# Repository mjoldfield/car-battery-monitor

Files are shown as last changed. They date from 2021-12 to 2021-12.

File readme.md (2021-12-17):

# Car battery monitor

My car tends to eat batteries! Sometimes, particularly during pandemic
summers many weeks pass without the car being used, and during this
time sometimes the battery discharges. I suspect the underlying
problem is that somewhere current is leaking to ground, but that seems
hard to fix. Instead, I’d be happy to just monitor the situation and
charge the battery if needed.

The car is usually parked in range of the home WiFi network, so a
convenient solution would be to have the car send me email about its
battery every once in while.

## code

All written in CircuitPython

## pcb

A PCB to hold tne TinyS2 and DC-DC converter boards, designed in KiCad.

## case

A 3D-printable case designed with OpenSCAD.

# Blog post

See [my blog](https://mjoldfield.com/atelier/2021/12/car-battery-monitor.html) for
more details.

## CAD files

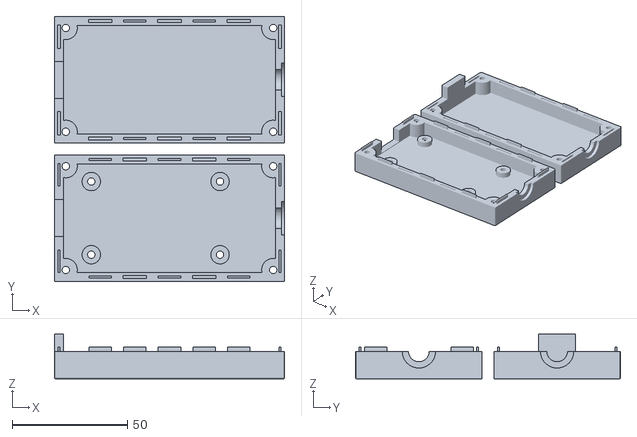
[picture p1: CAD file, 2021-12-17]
case/case.stl
100.0 x 115.0 x 19.5

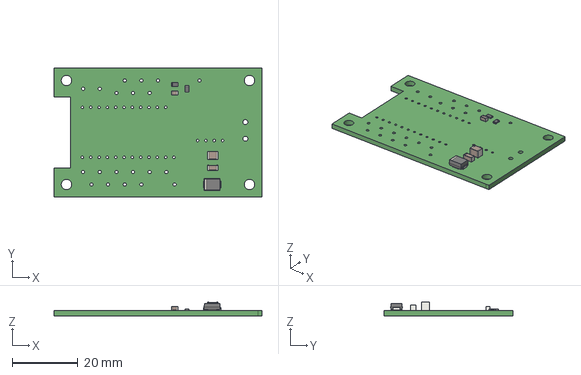
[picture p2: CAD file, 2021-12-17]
pcb/pcb.step
63.5 x 39.4 x 4.15 mm

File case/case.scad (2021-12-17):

include <BOSL/shapes.scad>
include <BOSL/transforms.scad>
include <BOSL/metric_screws.scad>

big   = 200;    // a big number guaranteed to get us out of the box
delta = 1;  // a small number to make sure we go through faces

$fn=50;

wall = 4.0;
size = [100,55,24];
    
board_width  = 65;
board_height = 40;
board_gap    = 0.5;

usb_step     = 0.5;
usb_width    = 16.0;
    
grommet_small = 9;
grommet_width = 2.5;
grommet_big   = 14.5;
    
pcb_mounting_x = 55.88;
pcb_mounting_y = 31.75;
pcb_offset_x   = -6.0;
pcb_offset_y   = 0;
    
standoff_h =  wall + 3.0;
standoff_d =  8;
    
screw_d_thread = 3.2;
screw_h_head   = 3.5;
screw_d_head   = 6.5;
nut_h_head     = 3.5;
nut_d_head     = 6.5;
    
case_screw_inset    =  5.0;
case_screw_diameter = 10.0;

teeth_w     = 1.0;
teeth_h     = 2.0;
teeth_l     = 10.0;
teeth_space = 0.2;
teetha_xs   = [-30,0,30];
teethb_xs   = [-15,15];
teetha_ys   = [-18.75,18.75];
teethb_ys   = [];

module b() {
    
    bd_dx = 0.5 * board_width  + board_gap;
    bd_dy = 0.5 * board_height + board_gap;
    
    cs_dx = 0.5 * size[0] - case_screw_inset;
    cs_dy = 0.5 * size[1] - case_screw_inset;       
    
    insize = size - [2 * wall, 2 * wall, 2 * wall];
    
    pcb_xs = [-0.5 * pcb_mounting_x + pcb_offset_x, 0.5 * pcb_mounting_x + pcb_offset_x];
    pcb_ys = [-0.5 * pcb_mounting_y + pcb_offset_y, 0.5 * pcb_mounting_y + pcb_offset_y];
        
    difference() {
    
        union() {
            difference()  {
                // main box
                cuboid(size, fillet=0.5);

                // hollowed out
                cuboid(insize);
                
                // Cable grommet
                xcyl(l = big, d = grommet_small, center=false);
                right(0.5 * size[0] - (wall - grommet_width))
                    xcyl(l = wall, d = grommet_big, center = false);
            };  
    
            // Mounting standoffs for PCB
            grid3d(xa = pcb_xs,
                   ya = pcb_ys,
                   za=[-0.5 * size[2]])
                cyl(h = standoff_h, d = standoff_d, center=false);
            
            // Screws to hold case together
            intersection() {
                cuboid(size, fillet=0.5);
                grid3d(xa=[-cs_dx,cs_dx], ya=[-cs_dy,cs_dy], za=[-0.5 * size[2]])
                  cyl(h = size[2], d = case_screw_diameter, center=false);
            };
            
        };
        
        // PCB
        span_cube([-bd_dx + pcb_offset_x, bd_dx + pcb_offset_x],
                  [-bd_dy + pcb_offset_y, bd_dy + pcb_offset_y], [
                -0.5 * size[2] + standoff_h,0]);
        
        // Holes in PCB standoffs        
        grid3d(xa=pcb_xs,
               ya=pcb_ys,
               za=[0])
               union() { 
                   down(0.5 * size[2] + delta)
                   union() {
                       cyl(h = standoff_h + 2 * delta, d=screw_d_thread, center=false);
                       cyl(h = screw_h_head + delta,   d=screw_d_head,   center=false);
                   }
               };
               
        // Holes for case screws
        grid3d(xa=[-cs_dx,cs_dx], ya=[-cs_dy,cs_dy], za=[0])
               union() {
                   cyl(h = 2 * big, d=screw_d_thread, center=true);
                   down(big)
                   cyl(h = big - 0.5 * size[2] + screw_h_head,   d=screw_d_head,   center=false);
                   zflip()
                   down(big)
                   cyl(h = big - 0.5 * size[2] + nut_h_head,     d=nut_d_head,     center=false, $fn=6);
               };       
    };
      
            


};


module teeth(xp,yp,xn,yn,pdir) {
    dx = 0.5 * (size[0] - wall);
    dy = 0.5 * (size[1] - wall);
    tlp = 0.5 * (teeth_l - teeth_space);
    tln = 0.5 * (teeth_l + teeth_space);
    twp = 0.5 * (teeth_w - teeth_space);
    twn = 0.5 * (teeth_w + teeth_space);
       
    difference() { 
        union() {
            children();
            grid3d(xa=xp,ya=[-dy,dy],za=[0])
                span_cube([-tlp,tlp],[-twp,twp],[0,pdir * (teeth_h - teeth_space)]); 
            grid3d(xa=[-dx,dx],ya=yp,za=[0])
                span_cube([-twp,twp],[-tlp,tlp],[0,pdir * (teeth_h - teeth_space)]); 
        };
        grid3d(xa=xn,ya=[-dy,dy],za=[0])
            span_cube([-tln,tln],[-twn,twn],[0,-pdir * (teeth_h + teeth_space)]); 
        grid3d(xa=[-dx,dx],ya=yn,za=[0])
                span_cube([-twn,twn],[-tln,tln],[0,-pdir * (teeth_h + teeth_space)]); 
    };
}

module usbslot() {
      span_cube([-(0.5 * size[0] + 1),-(0.5 * size[0] - wall - 1)],
                [-0.5 * usb_width,0.5 * usb_width],
                [-(0.5 * size[2] - wall - usb_step),1]);
};

module bb() {
    teeth(teetha_xs, teetha_ys, teethb_xs, teethb_ys, 1.0)
    intersection() {
        b(); 
        difference() {
            downcube(big);
            usbslot();
        };
    };
};
    
module bt() {
    teeth(teethb_xs, teethb_ys, teetha_xs, teetha_ys, -1.0)
    intersection() {
        b(); 
        union() {
            upcube(big);
            usbslot();
        };
    };
};
    

ydistribute(spacing=60) {
bb();   
xrot(180) bt();
};

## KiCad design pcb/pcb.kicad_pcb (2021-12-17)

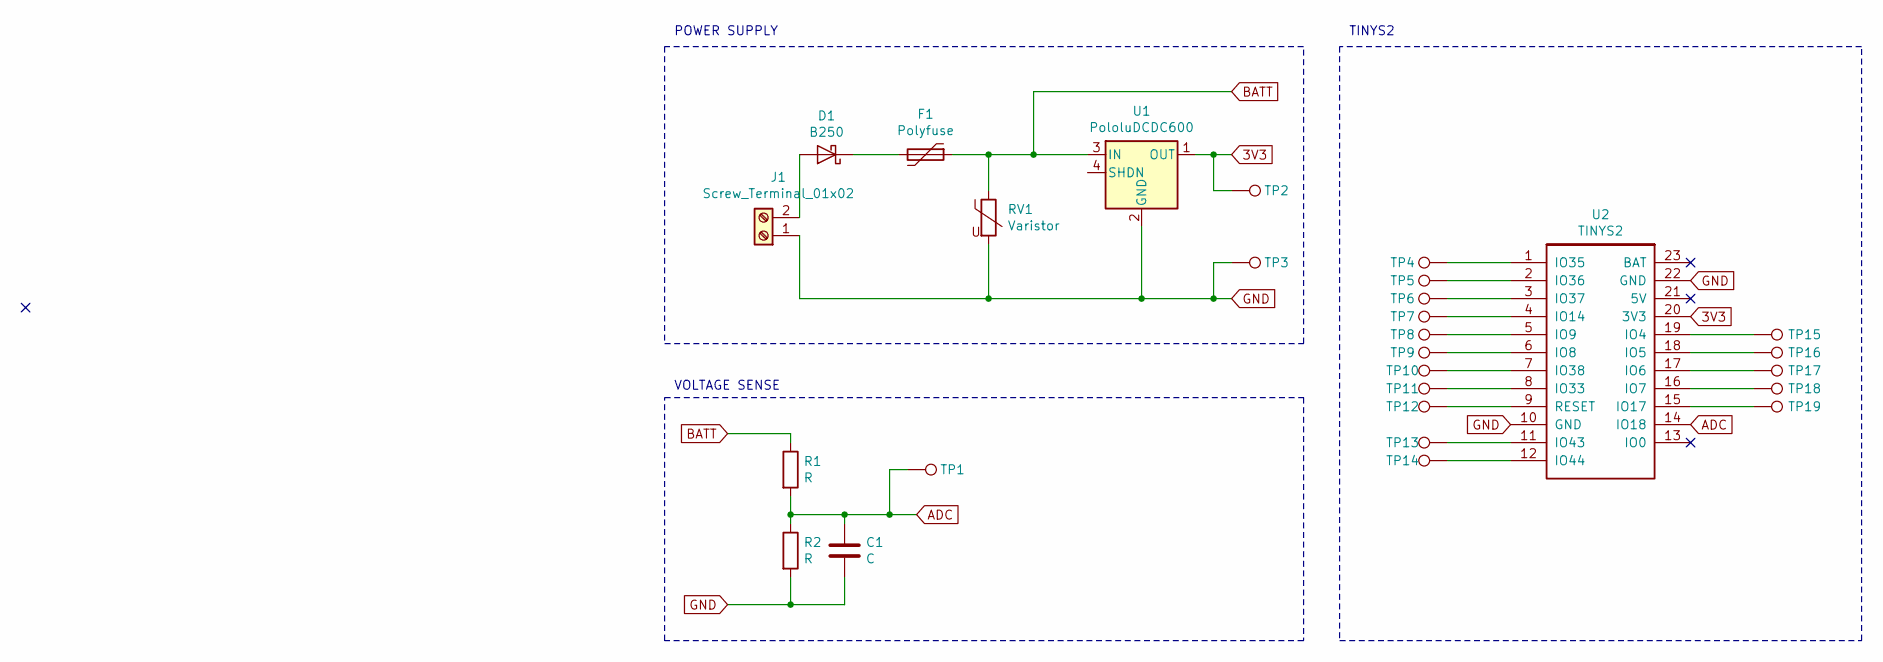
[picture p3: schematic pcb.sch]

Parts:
C1: C; C_0805_2012Metric_Pad1.15x1.40mm_HandSolder
D1: B250; D_SMB
F1: Polyfuse; C_1206_3216Metric_Pad1.42x1.75mm_HandSolder
J1: Screw_Terminal_01x02; TerminalBlock_bornier-2_P5.08mm
R1, R2: R; R_0805_2012Metric_Pad1.15x1.40mm_HandSolder
RV1: Varistor; C_1210_3225Metric_Pad1.42x2.65mm_HandSolder
TP1, TP2, TP3, TP4, TP5, TP6, TP7, TP8, TP9, TP10, TP11, TP12, TP13, TP14, TP15, TP16, TP17, TP18, TP19: TestPoint; TestPoint_THTPad_D2.0mm_Drill1.0mm
U1: PololuDCDC600; PololuDCDC4
U2: TINYS2

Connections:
3V3: TP2.1, U1.1 (OUT), U2.20 (3V3)
ADC: C1.1, R1.2, R2.1, TP1.1, U2.14 (IO18)
BATT: F1.1, R1.1, RV1.1, U1.3 (IN)
GND: C1.2, J1.1, R2.2, RV1.2, TP3.1, U1.2 (GND), U2.10 (GND), U2.22 (GND)
unnamed: D1.1 (K), F1.2
unnamed: D1.2 (A), J1.2
unnamed: TP4.1, U2.1 (IO35)
unnamed: TP5.1, U2.2 (IO36)
unnamed: TP6.1, U2.3 (IO37)
unnamed: TP7.1, U2.4 (IO14)
unnamed: TP8.1, U2.5 (IO9)
unnamed: TP9.1, U2.6 (IO8)
unnamed: TP10.1, U2.7 (IO38)
unnamed: TP11.1, U2.8 (IO33)
unnamed: TP12.1, U2.9 (RESET)
unnamed: TP13.1, U2.11 (IO43)
unnamed: TP14.1, U2.12 (IO44)
unnamed: TP15.1, U2.19 (IO4)
unnamed: TP16.1, U2.18 (IO5)
unnamed: TP17.1, U2.17 (IO6)
unnamed: TP18.1, U2.16 (IO7)
unnamed: TP19.1, U2.15 (IO17)

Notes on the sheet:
POWER SUPPLY
VOLTAGE SENSE
TINYS2

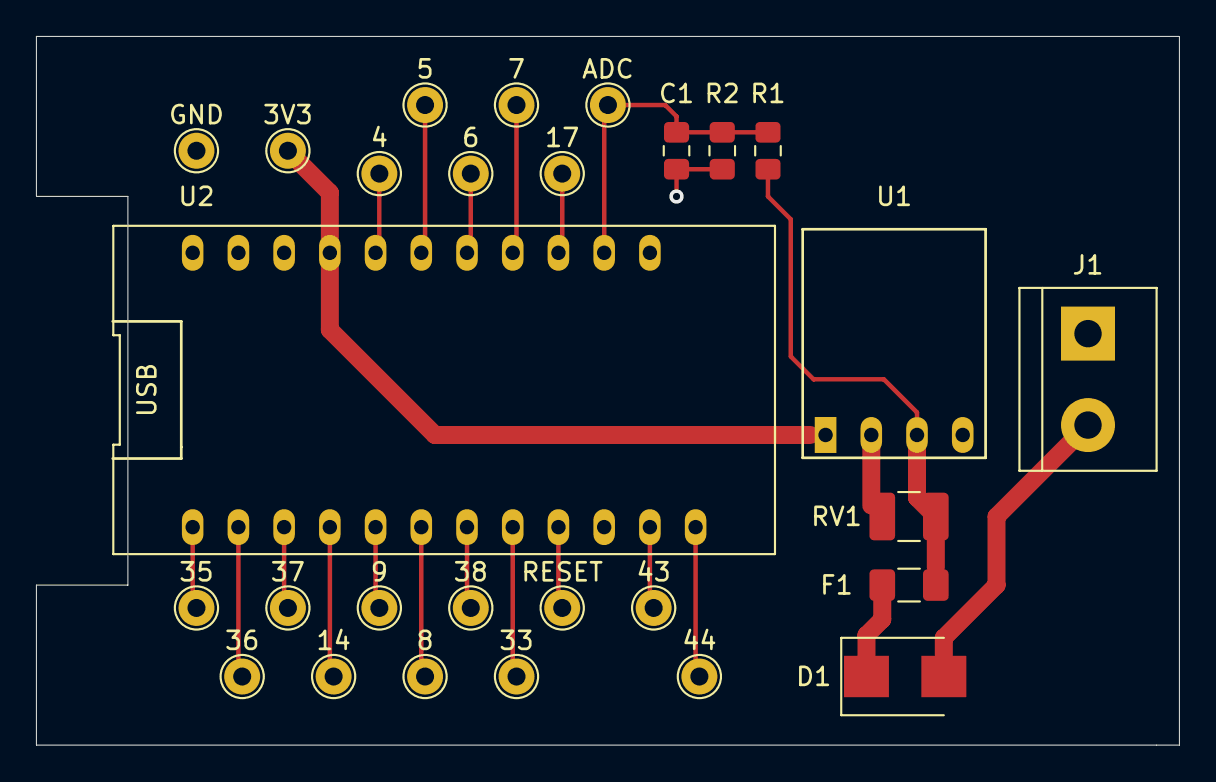
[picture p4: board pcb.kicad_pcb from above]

Board: 2 copper layers, 63.5 x 39.4 mm, 28 parts (0 on the bottom side), 22 nets.

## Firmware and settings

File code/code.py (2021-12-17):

# Write your code here :-)
import board
import time
import alarm
import tinys2
import neopixel
import digitalio
import analogio
import wifi
import socketpool
import math

from secrets import secrets

def wifi_connect():
    print("Connecting to AP...")
    try:
      wifi.radio.connect(secrets["ssid"], secrets["password"])
    except BaseException as e:
      print("Caught " + str(e))
      return False

    network = wifi.radio.ap_info
    print("Connected to {} via {}, RSSI = {}".format(network.ssid, network.authmode, network.rssi))
    print("My IP address is", str(wifi.radio.ipv4_address))
    return True

def mail_open_socket():
    server = secrets["smtp_server"]
    print("Connecting to mail server ", server)
    pool = socketpool.SocketPool(wifi.radio)
    sock = pool.socket()
    addr = (server, 25)
    sock.connect(addr)
    return sock

def mail_rxtx(s, msg):
    if msg is not None:
        print('> ' + msg)
        s.send(msg.encode('ascii') + b'\n')

    buff_size = 1024
    buff = bytearray(buff_size)
    s.recv_into(buff)
    x = buff.decode('ascii')
    print('< ' + x.rstrip())
    return x

def mail_send(m_subj, m_msg):
    m_from = secrets["mail_from"]
    m_to   = secrets["mail_to"]

    m_subj = secrets["subject"] + ": " + m_subj

    s = mail_open_socket()
    mail_rxtx(s, None)
    mail_rxtx(s, "HELO pico")
    mail_rxtx(s, "MAIL FROM:{}".format(m_from))
    mail_rxtx(s, "RCPT TO:{}".format(m_to))
    mail_rxtx(s, "DATA")
    mail_rxtx(s, "From: {}\nTo: {}\nSubject: {}\n\n{}\n.".format(m_from, m_to, m_subj, m_msg))

def adcraw_to_voltage(raw):
    v = 4.0309 * (raw / 10000) + 0.8814
    print("raw {} => {}V".format(raw,v))
    return v

def read_voltage():
    v_low  = 11.6
    v_high = 13.0

    adc = analogio.AnalogIn(board.IO18)

    hn_samp = 32
    raws = [ adc.value for i in range(2 * hn_samp + 1) ]
    raws_s     = sorted(raws)
    raw_median = raws_s[hn_samp]

    vs = [ adcraw_to_voltage(raw) for raw in raws_s ]
    v_median = vs[hn_samp]
    v_mean   = sum(vs) / len(vs)
    v_var    = sum([ (v - v_mean)**2 for v in vs ]) / len(vs)
    v_sd     = math.sqrt(v_var)

    status = "Unknown"
    if v_median < v_low:
        status = "WARNING LOW BATTERY"
    elif v_median > v_high:
        status = "WARNING HIGH BATTERY"
    else:
        status = "GOOD BATTERY"

    subj = "{}: {} ± {}V; {}V".format(status, v_mean, v_sd, v_median)
    body = "Median raw: " + str(raw_median) + "\nReadings\n" + "".join([ str(r) + "\n" for r in raws ]) + "\n"

    return (subj, body)

pixel  = neopixel.NeoPixel(board.NEOPIXEL, 1, brightness = 0.3, auto_write = True, pixel_order = neopixel.GRB)

def leds_init():
    global pixel
    pixel[0] = (0,0,0)
    tinys2.set_pixel_power(True)

def leds_close():
    global pixel
    tinys2.set_pixel_power(False)

def leds_set(rgb):
    global pixel
    pixel[0] = rgb

print("Battery Test")

t0 = time.monotonic()

leds_init()
leds_set((0,255,0))

time.sleep(5.0)

(subj, body) = read_voltage()
print(subj)
print(body)

leds_set((0,0,255))
connected = wifi_connect()
if connected:
    mail_send(subj, body)
print(subj)

leds_close()

t1 = time.monotonic()

print("Awake for {}s".format(t1 - t0))


print("Deep sleep")
sleep_time = 6 * 3600.0

time_alarm = alarm.time.TimeAlarm(monotonic_time=time.monotonic() + sleep_time)
alarm.exit_and_deep_sleep_until_alarms(time_alarm)
